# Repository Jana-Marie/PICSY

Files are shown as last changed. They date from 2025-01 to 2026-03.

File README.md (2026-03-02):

# PICSY

**UNDER DEVELOPMENT...**

An ESP32 based Pixel-Art-Camera, shooting color-indexed pixel art alike PNGs directly onto an SD card.

<table>
  <tbody>
    <tr>
      <td colspan="2">
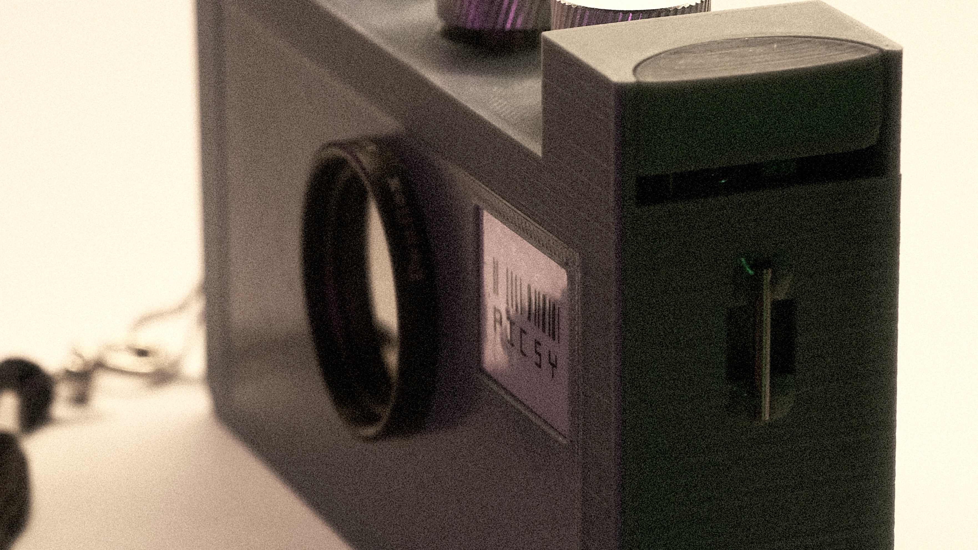
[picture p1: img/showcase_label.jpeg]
        
      </td>
    </tr>
    <tr>
      <td>
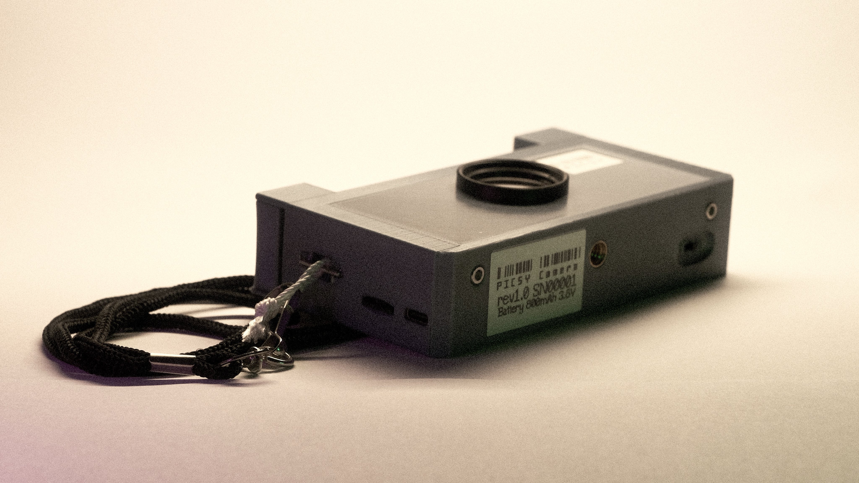
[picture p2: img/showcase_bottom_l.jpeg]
        
      </td>
      <td>
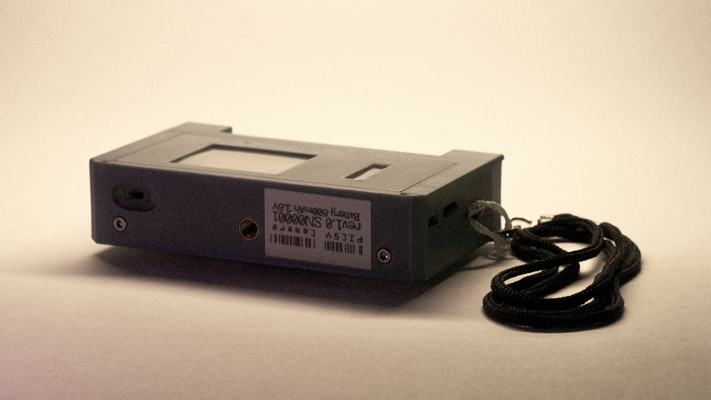
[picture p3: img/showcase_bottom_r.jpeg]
        
      </td>
    </tr>
    <tr>
      <td colspan="2">
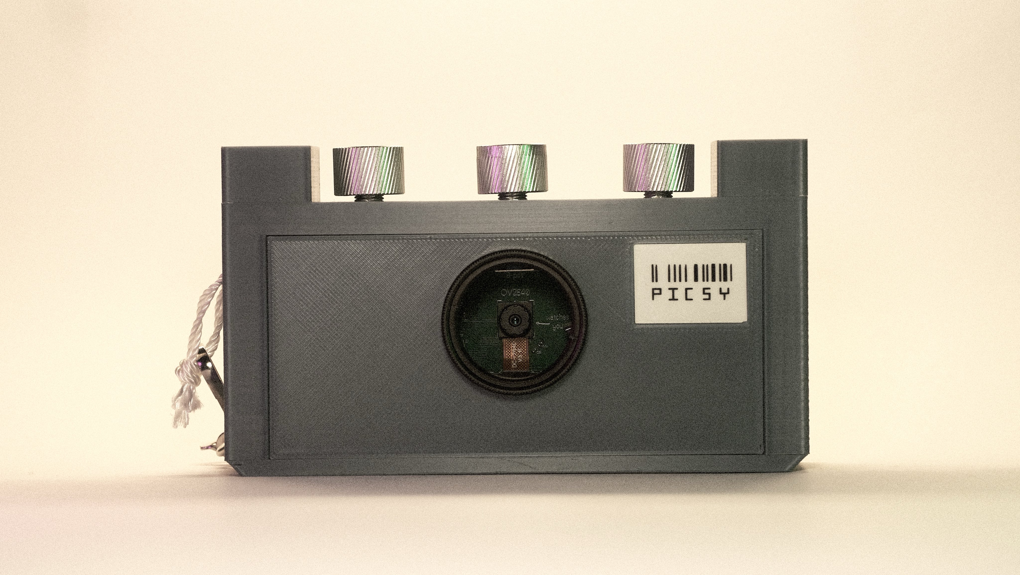
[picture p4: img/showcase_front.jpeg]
        
      </td>
    </tr>
    <tr>
      <td colspan="2">
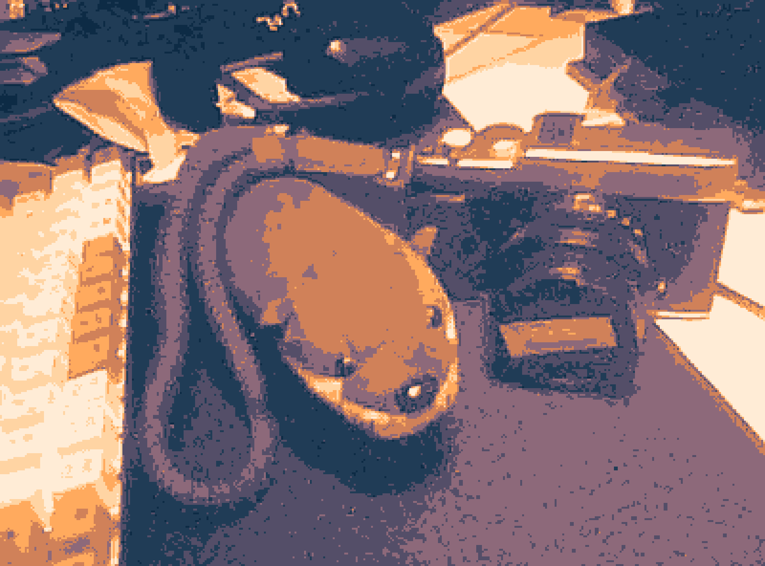
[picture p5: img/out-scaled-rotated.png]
        
      </td>
    </tr>
    <tr>
      <td>
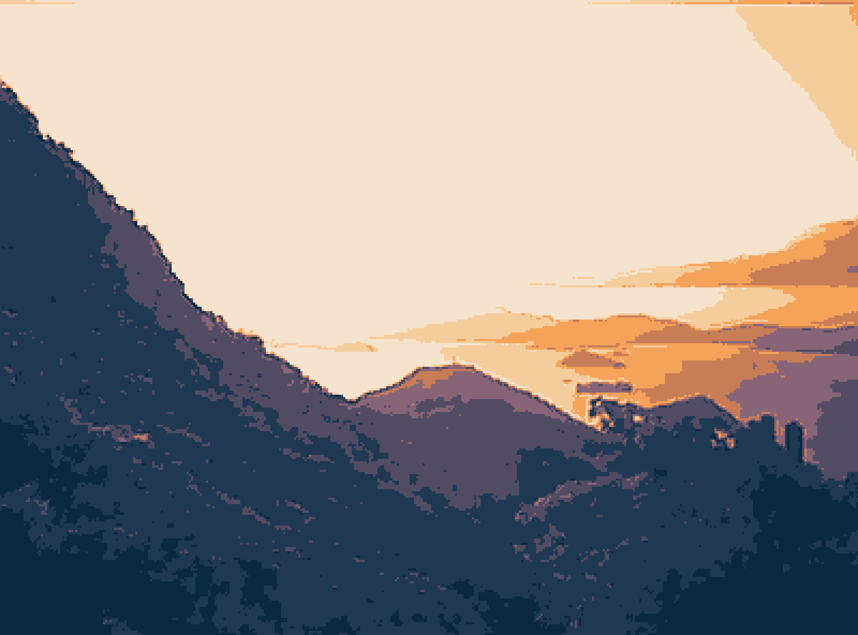
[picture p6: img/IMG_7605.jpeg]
        
      </td>
      <td>
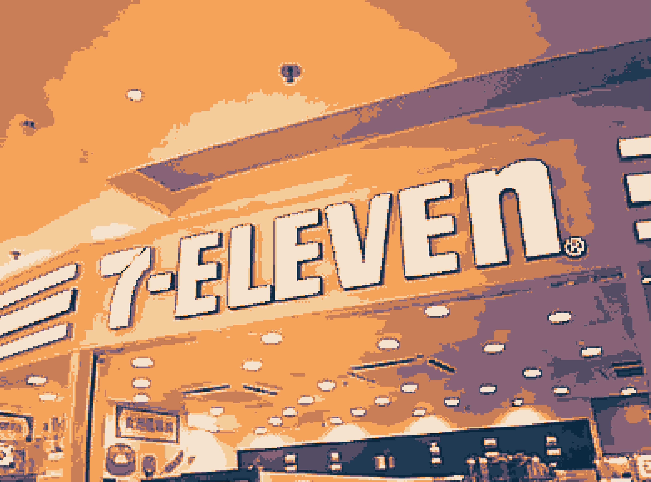
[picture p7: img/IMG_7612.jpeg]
        
      </td>
    </tr>
    <tr>
      <td colspan="2">
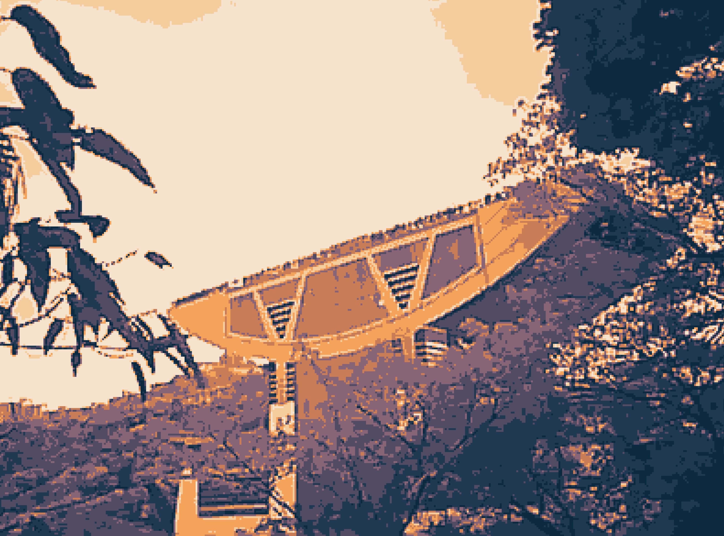
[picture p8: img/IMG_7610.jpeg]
        
      </td>
    </tr>
  </tbody>
</table>

### Setup

Flash micropython as per [/main/micropython-bin](https://github.com/Jana-Marie/PICSY/tree/main/micropython-bin), afterwards copy `ubuf2png.py` onto the ESP32-CAM with `ampy -p /dev/ttyUSB0 -b 115200 put ubuf2png.py`

### Usage

This is WIP and will be moved to saving the PNG to a SD card directly soon.

#### Manual usage

Place an SD card into the SD-Card slot and run

```
ampy -p /dev/ttyUSB0 -b 115200 run boot.py
```

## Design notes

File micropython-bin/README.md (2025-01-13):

# flashing

```
esptool --chip esp32 erase_flash

esptool --chip esp32 -b 460800 --before default_reset --after hard_reset write_flash --flash_mode dio --flash_size 4MB --flash_freq 40m 0x1000 bootloader.bin 0x8000 partition-table.bin 0x10000 micropython.bin
```

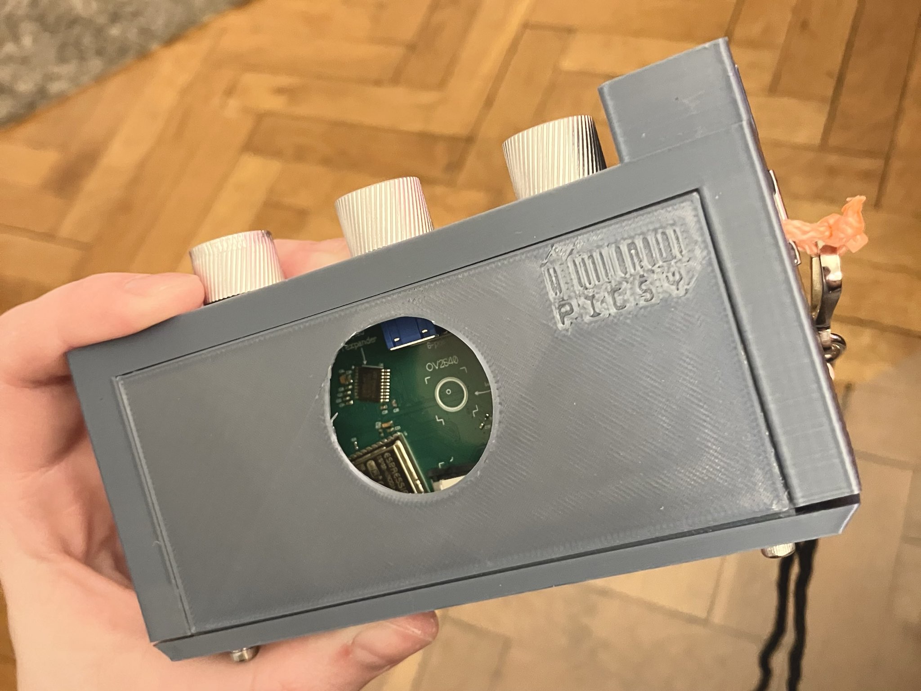
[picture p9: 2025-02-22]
img/wip_3.jpeg

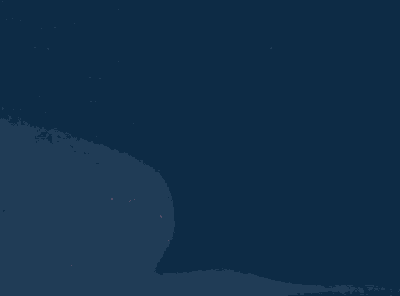
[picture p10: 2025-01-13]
img/out.png

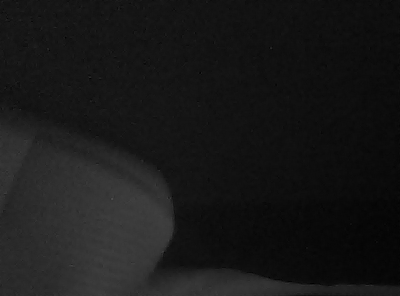
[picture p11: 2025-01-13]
img/img.png

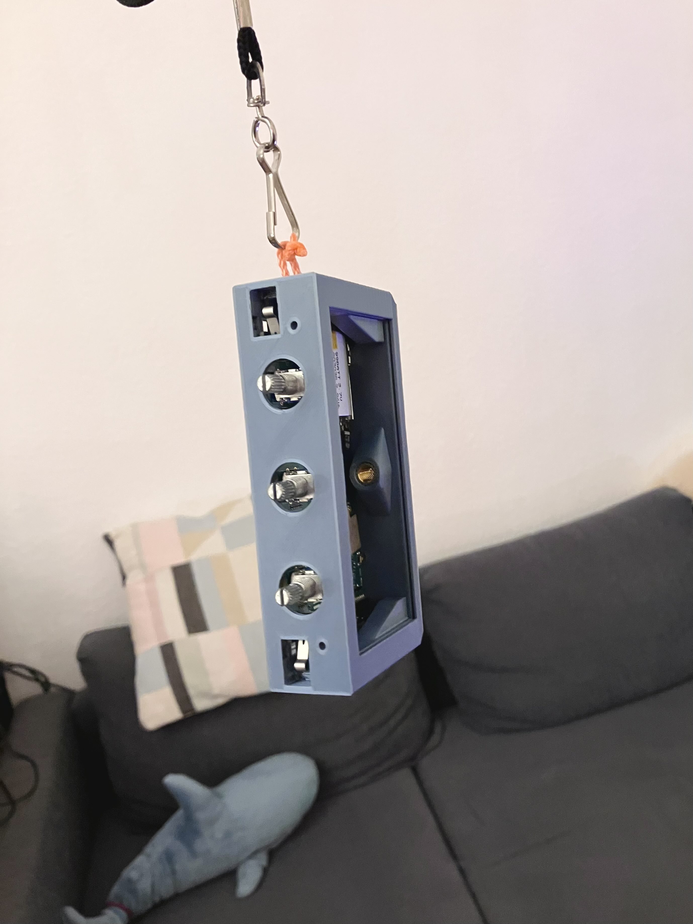
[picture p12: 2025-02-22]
img/wip_2.jpeg

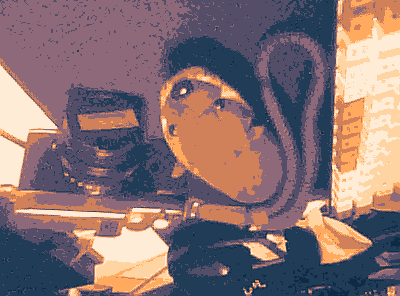
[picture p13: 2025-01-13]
img/out2.png

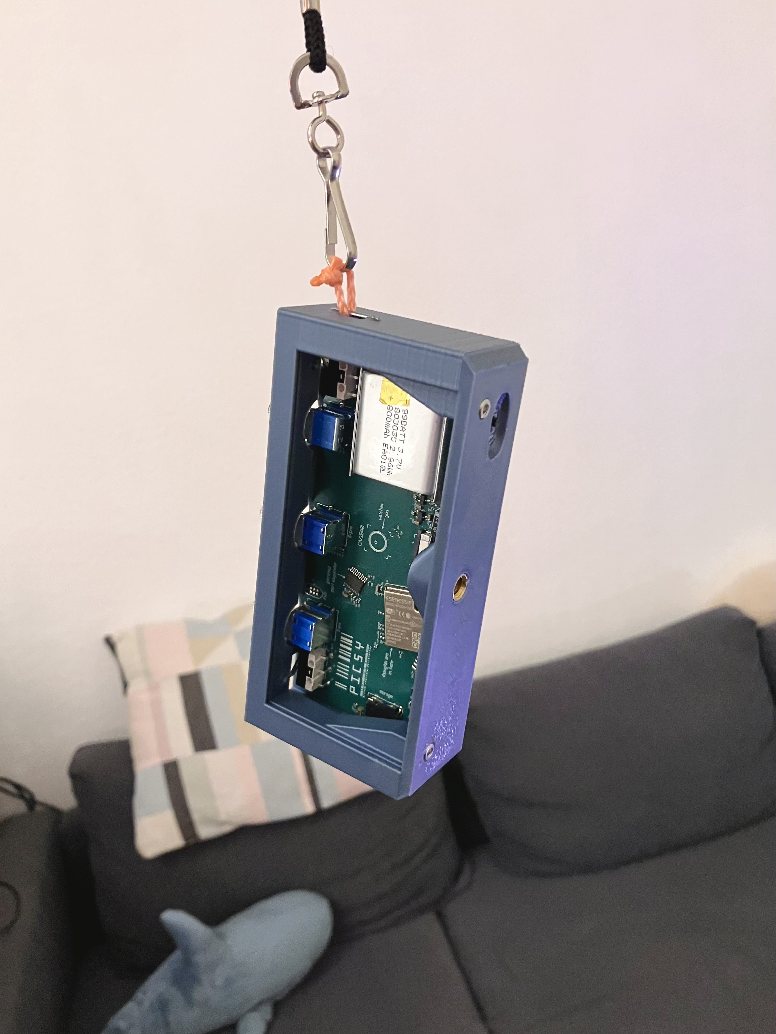
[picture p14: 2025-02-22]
img/wip_1.jpeg

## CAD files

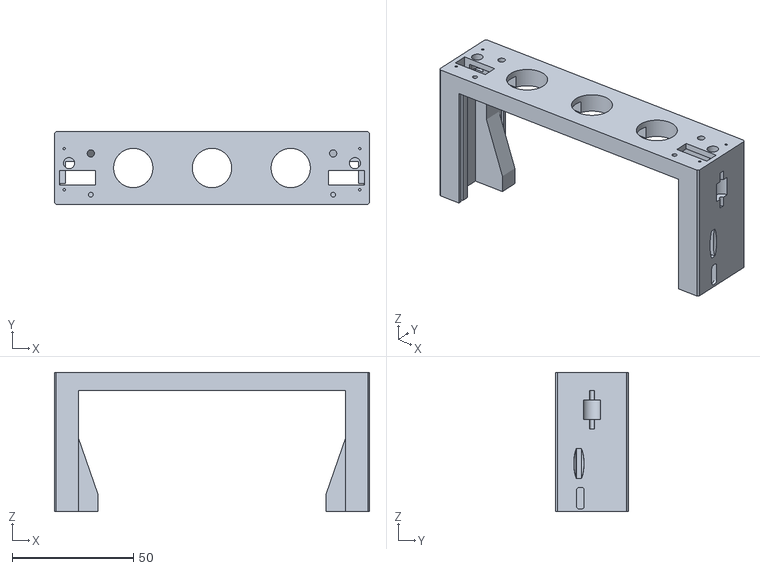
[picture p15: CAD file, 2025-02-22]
CAD/STL/PICSY_main_body.stl
130.0 x 30.0 x 57.4

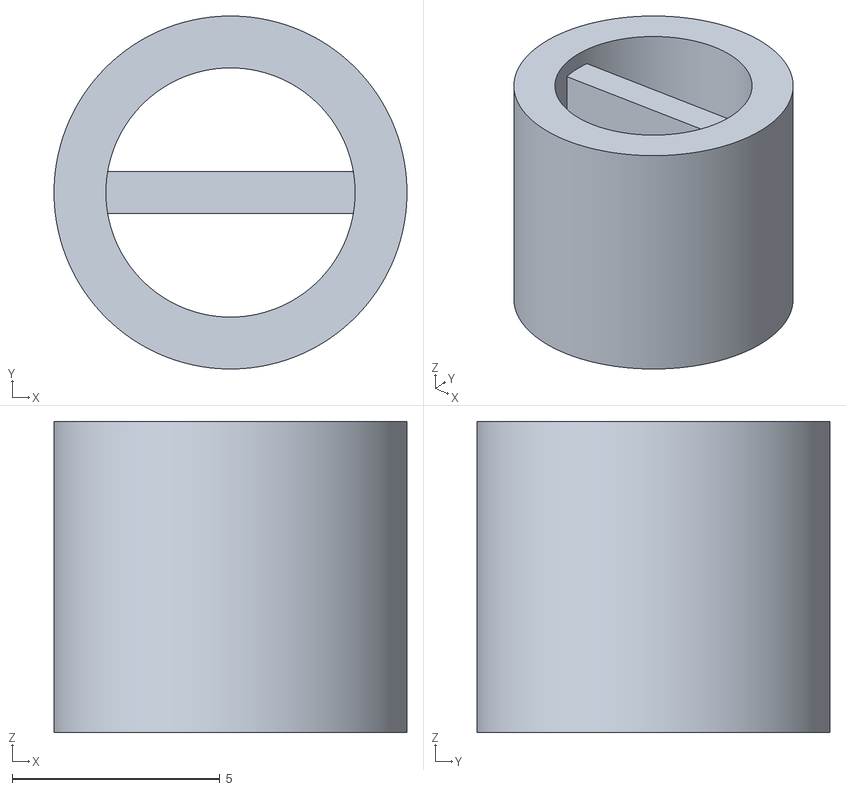
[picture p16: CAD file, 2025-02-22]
CAD/STL/PICSY_button_inlay.stl
8.50 x 8.50 x 7.50

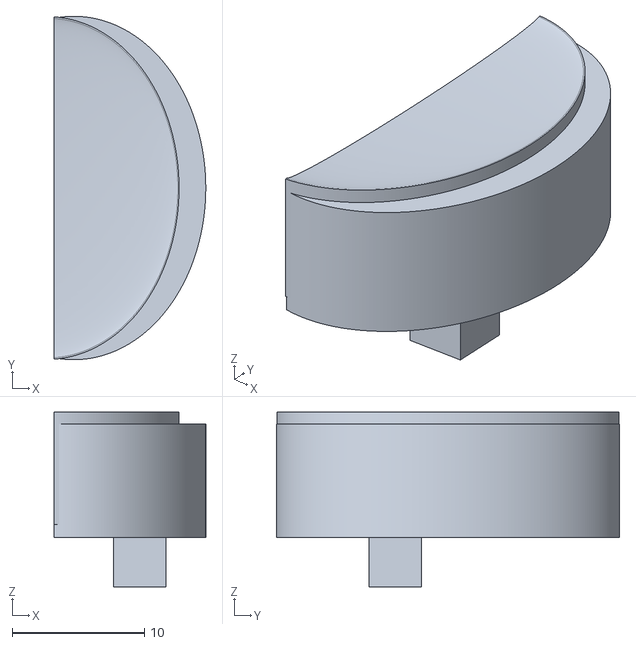
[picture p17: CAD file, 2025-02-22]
CAD/STL/PICSY_trigger_button_r.stl
11.5 x 26.0 x 13.2

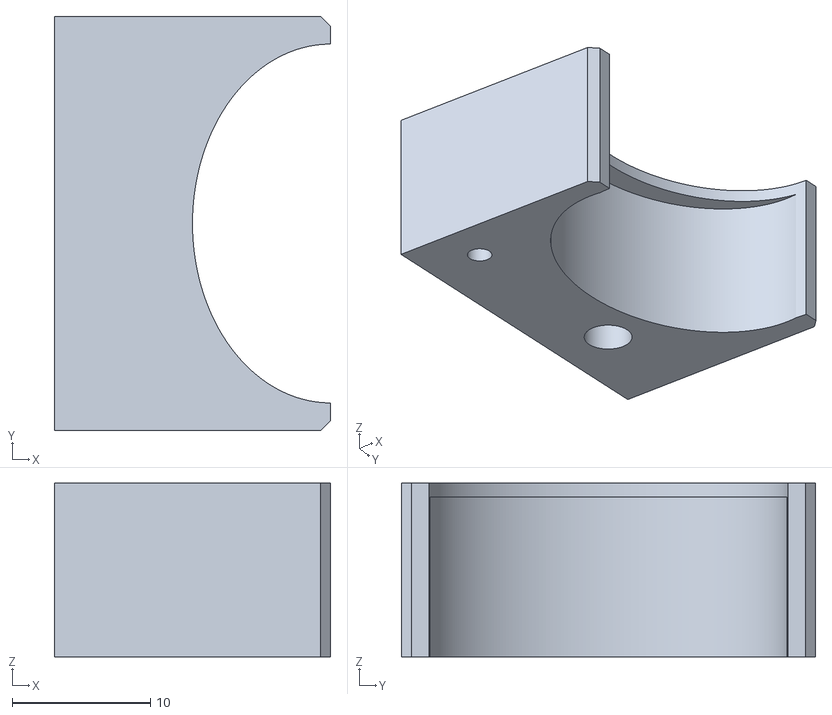
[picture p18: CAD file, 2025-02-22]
CAD/STL/PICSY_trigger_body_l.stl
20.0 x 30.0 x 12.6

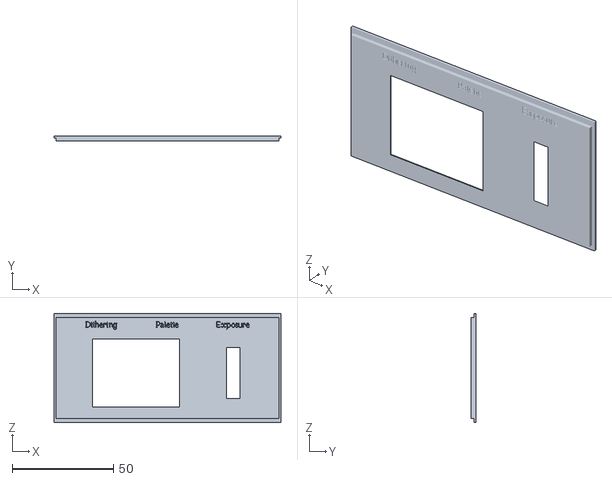
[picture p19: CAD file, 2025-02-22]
CAD/STL/PICSY_back_plate.stl
112.0 x 2.50 x 54.0

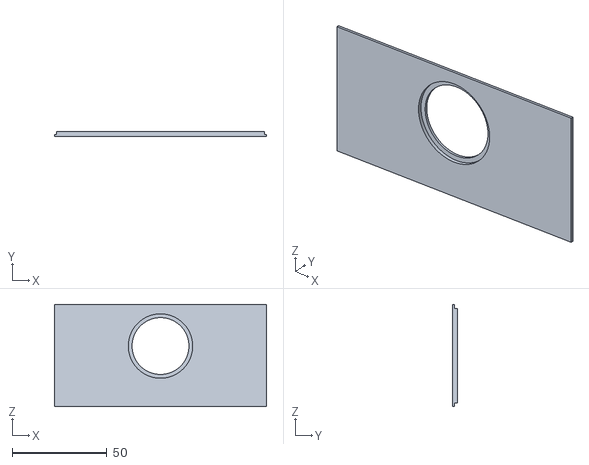
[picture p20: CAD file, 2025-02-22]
CAD/STL/PICSY_front_plate.stl
112.0 x 2.50 x 54.0

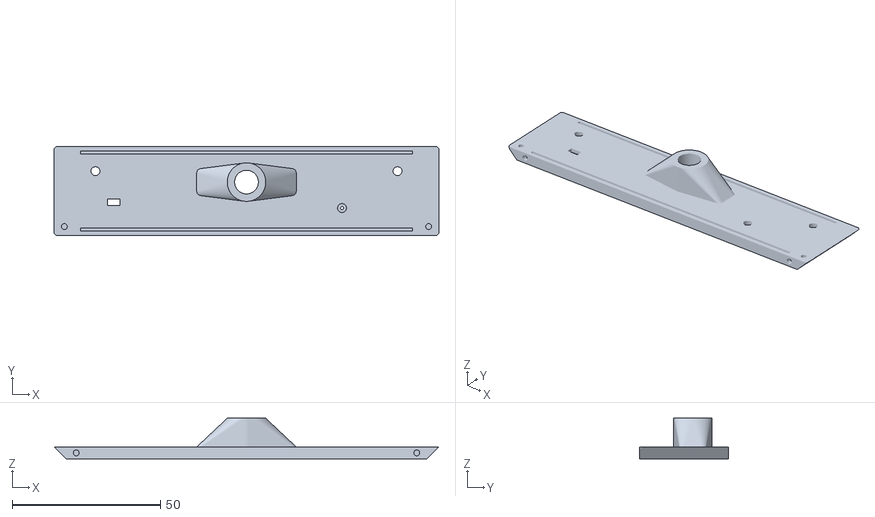
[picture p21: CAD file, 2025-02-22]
CAD/STL/PICSY_bottom_cover.stl
130.0 x 30.0 x 13.7

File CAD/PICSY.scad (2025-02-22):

$fn=30;

if($preview){
  *translate([0,-6.4,0])rotate([90,0,0])picsy_hw(2);
  assembly();
}else{
  $fn=300;
  *mirror([0,0,0])translate([130/2,0,70])trigger_body();
  *mirror([0,0,0])translate([130/2,0,70])trigger_button();
  front_plate();
}

// ######## assembly ########
module assembly(){
  main_body(true);
  translate([0,0,0])trigger_button_body_l();
  translate([0,0,0])trigger_button_body_r();
  translate([0,-12.5,0])back_plate();
  translate([0,12.5,0])front_plate();
  bh=4;
  translate([0,0,-bh])bottom_cover(bh);
}

// ######## main ########
module main_body(finish=false){
  h=70-12.6;
  t=30;l=130;
  color("MediumAquamarine")
  difference(){
    union(){
      // main body
      translate([0,0,h/2])cube([l,t,h],center=true);
    }union(){
      // main notch
      translate([0,0,50/2-0.1])cube([110,t+2,50.1],center=true);
      // flaps
      translate([0,t/2-2,52.2/2])cube([112.2,1,52.2],center=true);
      translate([0,-t/2+2,52.2/2])cube([112.2,1,52.2],center=true);
      // pcb & parts
      translate([0,-7.3,55/2-0.1])cube([125.6,1.75,55.4],center=true);
      translate([0,-7.3+4,55/2-0.1])cube([121,12,55.1],center=true);
      // usb-port
      usbcd=2.5;
      translate([60,3.2/2-6.4,4.5+1])rotate([0,90,0])minkowski(){
        cylinder(d=usbcd,h=1);
        cube([9-usbcd,3.2-usbcd,9.5],center=true);
      }
      translate([58,3.2/2-6.4,4.5+1-5.5])rotate([0,90,0])minkowski(){
        cylinder(d=usbcd,h=1);
        cube([20-usbcd,3.2-usbcd,9.5],center=true);
      }
      // sd card
      translate([l/2,2/2-6.4,5+14.8])cube([12.2,2.2,12.4],center=true);
      translate([l/2-9,2/2-6.4,5+8])cube([12.2,2.2,12.4],center=true);
      intersection(){
        translate([l/2,2/2-6.4,5+14.8])scale([2,4.2,14.2])sphere(d=1);
        translate([l/2,2/2-6.4,5+14.8])cube([12,6,12.4],center=true);
      }
      // lanyard
      for(i = [-1:2:1]){
        translate([130/2*i,0,34])cylinder(d=2,h=16);
        translate([130/2*i,0,34+4])cylinder(d=7,h=8);
      }
      // pins
      for(i = [-1:2:1]){
        translate([l/2*i-15*i,-11,h-(18-11.6)])cylinder(d=2,h=18);
        // spring
        translate([l/2*i-6*i,2,h-(18-11.6)])cylinder(d=4.6,h=10);
        // trigger button
        translate([l/2*i-4*i,8,h-10])cylinder(d=1,h=16);
        translate([l/2*i-4*i,-9,h-10])cylinder(d=1,h=16);
      }
      // vertical pins
      for(i = [-1:2:1]){
        translate([(l-7)/2*i,-12,-1.5])rotate([0,0,0])cylinder(d=2,h=30);
      }
      // trigger
      for(i = [-1:2:1]){
        translate([(l/2-15/2-2)*i,-4,-8/2+h+1])cube([15,6,8],center=true);
        *translate([(l/2-15/2-4.5)*i,-8,-4/2+h-1])cube([4,6,4],center=true);
        translate([(l/2-15)*i,6,h-20])cylinder(d=3,h=25);
      }
      // knobs
      for(i = [-1:1:1]){
        translate([32.5*i,0,40])cylinder(d=16.2,h=25);
      }
      // edges
      if(finish){
        corn_z=1;
        for(i = [-1:2:1]){
          for(j = [-1:2:1]){
            translate([l/2*i,t/2*j,h/2])rotate([0,0,45])cube([corn_z,corn_z,h+2],center=true);
          }
        }
      }
    }
  }
  sl=8;
  color("MediumAquamarine")
  for(i = [0:1:1]){
    mirror([i,0,0])
    difference(){
      union(){
        hull(){
          translate([110/2-sl/2,sl/2+2.7,7/2])cube([sl,sl,7],center=true);
          translate([110/2+1/2,sl/2+2.7,30/2])cube([1,sl,30],center=true);
        }
      }union(){
        translate([110/2-sl/2,sl/2+2.7,-0.5])cylinder(d=3.9,h=8);
        translate([110/2-sl/2,sl/2+2.7,-0.5])cylinder(d=4.05,h=2);
      }
    }
  }
}

// ######## bottom cover ########
module bottom_cover(h){
  t=30;l=130;
  color("PaleGoldenrod")
  difference(){
    union(){
      // body
      translate([0,0,h/2])cube([l,t,h],center=true);
      // 1/4"
      hull(){
        translate([0,3,0])cylinder(d=13,h=13.7);
        translate([0,3,1/2])cube([40,8,1],center=true);
      }
    }union(){
      // flaps
      translate([0,t/2-2,-2/2+h])cube([112.2,1,2.2],center=true);
      translate([0,-t/2+2,-2/2+h])cube([112.2,1,2.2],center=true);
      // big corners
      for(i = [-1:2:1]){
        translate([l/2*i,0,0])rotate([0,45,0])cube([sqrt(h*h+h*h),t+2,sqrt(h*h+h*h)],center=true);
      }
      // smol corners
      corn_z=1;
      for(i = [-1:2:1]){
        for(j = [-1:2:1]){
          translate([l/2*i,t/2*j,h/2])rotate([0,0,45])cube([corn_z,corn_z,h+2],center=true);
        }
      }
      // screws
      for(i = [-1:2:1]){
        translate([(110/2-8/2)*i,8/2+2.7,-0.5])cylinder(d=3,h=8);
        translate([(110/2-8/2)*i,8/2+2.7,-0.5])cylinder(d=5.5,h=3.5);
      }
      // horizontal pins
      for(i = [-1:2:1]){
        translate([(l-15)/2*i,10,2])rotate([90,0,0])cylinder(d=2,h=30);
      }
      // vertical pins
      for(i = [-1:2:1]){
        translate([(l-7)/2*i,-12,3])rotate([0,0,0])cylinder(d=2,h=30);
      }
      // reset
      translate([32.25,-5.75,-0.5])cylinder(d=1,h=8);
      translate([32.25,-5.75,h-1.9])cylinder(d=3,h=2);
      // switch
      translate([-44.75,-3.75,h/2])cube([4.22,2.2,h+1],center=true);
      translate([-44.75,-3.75,0])minkowski(){
        cube([4,2,1],center=true);
        scale([14,8,4])sphere(d=1);
      }
      // 1/4"
      translate([0,3,-0.5])cylinder(d=8,h=14.2);
      translate([0,3,-0.5])cylinder(d2=8,d1=9,h=1);
    }
  }
}

// ######## trigger buttons ########
module trigger_button_body_r(){
  mirror([1,0,0])translate([130/2,0,70])trigger_body();
  mirror([1,0,0])translate([130/2,0,70])trigger_button();
}

module trigger_button_body_l(){
  mirror([0,0,0])translate([130/2,0,70])trigger_body();
  *mirror([0,0,0])translate([130/2,0,70])trigger_button();
}

module trigger_body(){
  color("CornflowerBlue")
  difference(){
    union(){
      // height 12.6!!
      translate([-(130-90)/2/2,0,-12.6/2])cube([(130-90)/2,30,12.6],center=true);
      // counter
      *translate([-12,-7.8,-4/2-12.5])cube([3.8,2,4],center=true);
      *hull(){
        translate([-12,-7.8-1,-1/2-12.5-1.2])cube([3.8,2,1],center=true);
        translate([-12,-7.8,1/2-12.5-4])cube([3.8,2,1],center=true);
      }
    }union(){
      // cutouts
      translate([0,0,-13.6])scale([20,26,1])cylinder(d=1,h=14.6);
      translate([-2,0,-13.6])scale([20,26,1])cylinder(d=1,h=12.6);
      *intersection(){
        translate([0,0,-15])scale([20,26,1])cylinder(d=1,h=25);
        translate([-20/2-0.5,0,-12.8/2-0.1])cube([20,30,12.8],center=true);
      }
      translate([0,0,0])cube([1.5,1.5,10],center=true);
      // screw
      translate([-15,6,-0.5-12.6])cylinder(d=3.9,h=9);
      // pin
      translate([-15,-11,-19])cylinder(d=2,h=18);
      // edges
      corn_z=1;
      for(j = [-1:2:1]){
        translate([0,30/2*j,-12.6/2])rotate([0,0,45])cube([corn_z,corn_z,12.6+2],center=true);
      }
    }
  }
}

module trigger_button(){
  color("IndianRed")
  difference(){
    union(){
      // main button
      intersection(){
        translate([0,0,-8.6])scale([19.95,25.95,1])cylinder(d=1,h=9.6);
        translate([-20/2-0.5,0,-12.8/2-0.1])cube([19.95,29,12.8],center=true);
      }
      intersection(){
        translate([-2,0,-9.6])scale([20,26,1])cylinder(d=1,h=8.6);
        translate([-20/2-0.5,0,-12.8/2-0.1])cube([19.95,29,12.8],center=true);
      }
      // microswitch contactor
      translate([-4/2-5,-4,2.5/2-12.6])cube([4,4,4],center=true);
      *translate([-10/2-3,-4,-2.5/2-12.6])cube([10,4,2.5],center=true);
      *hull(){
        translate([-4/2-3,-4,2.5/2-12.6])cube([4,4,2.5],center=true);
        translate([-4/2-1,-2,-2.5/2-5])cube([4,15,2.5],center=true);
      }
    }union(){
      // sink for finger
      translate([0,0,0])scale([19.95,25.95,1.5])sphere(d=1);
      // spring
      translate([-6,2,-12])cylinder(d=4.6,h=10);
      // pins
      translate([-4,8,-17.5])cylinder(d=1,h=16);
      translate([-4,-9,-17.5])cylinder(d=1,h=16);
    }
  }
}

// ######## plates ########
module front_plate(){
  color("RosyBrown")
  difference(){
    union(){
      translate([0,1/2,54/2-2])cube([112,1,54],center=true);
      translate([0,1.5/2+1,49.8/2])cube([109.8,1.5,49.8],center=true);
    }union(){
      // lens
      translate([0,-1,30])rotate([-90,0,0])cylinder(d=30,h=6);
      //translate([0,-1,30])rotate([-90,0,0])cylinder(d=34,h=2.5);
      // text
      //translate([-29,2.2,36])rotate([90,0,180])linear_extrude(height=0.5)text("PICSY", font="Pixelary");
      translate([-39,1/2+1.8,38])cube([25,1,18],center=true);
    }
  }
   if($preview){
    translate([0,3,30])rotate([-90,0,0])uv_filter_30mm();
  }
}
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

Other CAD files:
CAD/STL/PICSY_trigger_button_l.stl
CAD/STL/PICSY_trigger_body_r.stl
CAD/STL/PICSY_front_plate_empty_square.stl

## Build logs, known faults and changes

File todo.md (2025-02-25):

- **ESP32**
  - [ ] Image processing
    - [x] ~~Fix buffer swap issue, check if it still persists~~
    - [ ] Increase processing speed
  - [ ] UI
    - [x] ~~Trigger pin irq~~
    - [ ] Somehow upscale images by 4x
      - Added an external upscaler via js/html for now!
    - [ ] Add webserver to view and transmit images
    - [ ] Add palette display driver
    - [ ] Implement palette display UI
    - [ ] Add live-view display driver
    - [ ] Implement live view
    - [ ] Bodge an LED until next PCB rev
  - [ ] Coprocessor
    - [x] ~~Read trigger pin~~
    - [ ] Add co-processor communication (I2C)
    - [ ] Co-processor flashing via I2C
  - [ ] Settings
    - [x] ~~add camera settings code~~
    - [ ] Read settings from SD card (YAML/JSON)
    - [ ] Add more, selectable color palettes
    - [ ] Add dithering (InDi)
    - [ ] Nearest color matching, if possible
  - [ ] Misc
    - [ ] Check SD interface speed, is single lane fast enough to free pins?

- **STM32**
  - [x] ~~Add initial fw~~
  - [ ] I2C
    - [x] ~~Implement functionality~~
    - [x] ~~Define registermap~~
    - [ ] Sticky interrupts for rotary switches
  - [x] ~~ADC~~
    - [x] ~~Add all ADC channels~~
    - [x] ~~Bin the rotary encoders~~
    - [x] ~~Implement VBAT calculation~~
  - [x] ~~Trigger pins~~
    - [x] ~~Add l-r trigger pins~~
    - [x] ~~have a direct trigger pin interrup pass-through~~
  - [x] ~~Displays~~
    - [x] ~~Add CS pins, inactive high~~
    - [x] ~~Add RST pin~~
  - [ ] I2C bootloader

- **Hardwre**
  - [ ] rev1.1
    - [x] ~~Fix PSRAM layout in schematic~~
    - [x] ~~Cam clock pin 100nF → 15nF~~
    - [ ] Add status LEDs
    - [ ] Add display backlight control
    - [ ] Update ESP32 to a more modern module with internal PSRAM
    - [x] ~~Swap UART pins~~
    - [ ] Implement changes on PCB
    - [ ] PCB font sizes are too small
    - [ ] STM32 nRST pin needs pullup
    - [ ] Display 2 has the wrong connector
  - [ ] Clean up schematic
  - [ ] DFM

- **Web**
  - [ ] Build an image upscaler
    - [x] Build a web-app
    - [ ] Embed it onto the ESP32
    - [ ] Add boot screens for web-app solution

- **Documentation**
  - [ ] Add documentation as we go along

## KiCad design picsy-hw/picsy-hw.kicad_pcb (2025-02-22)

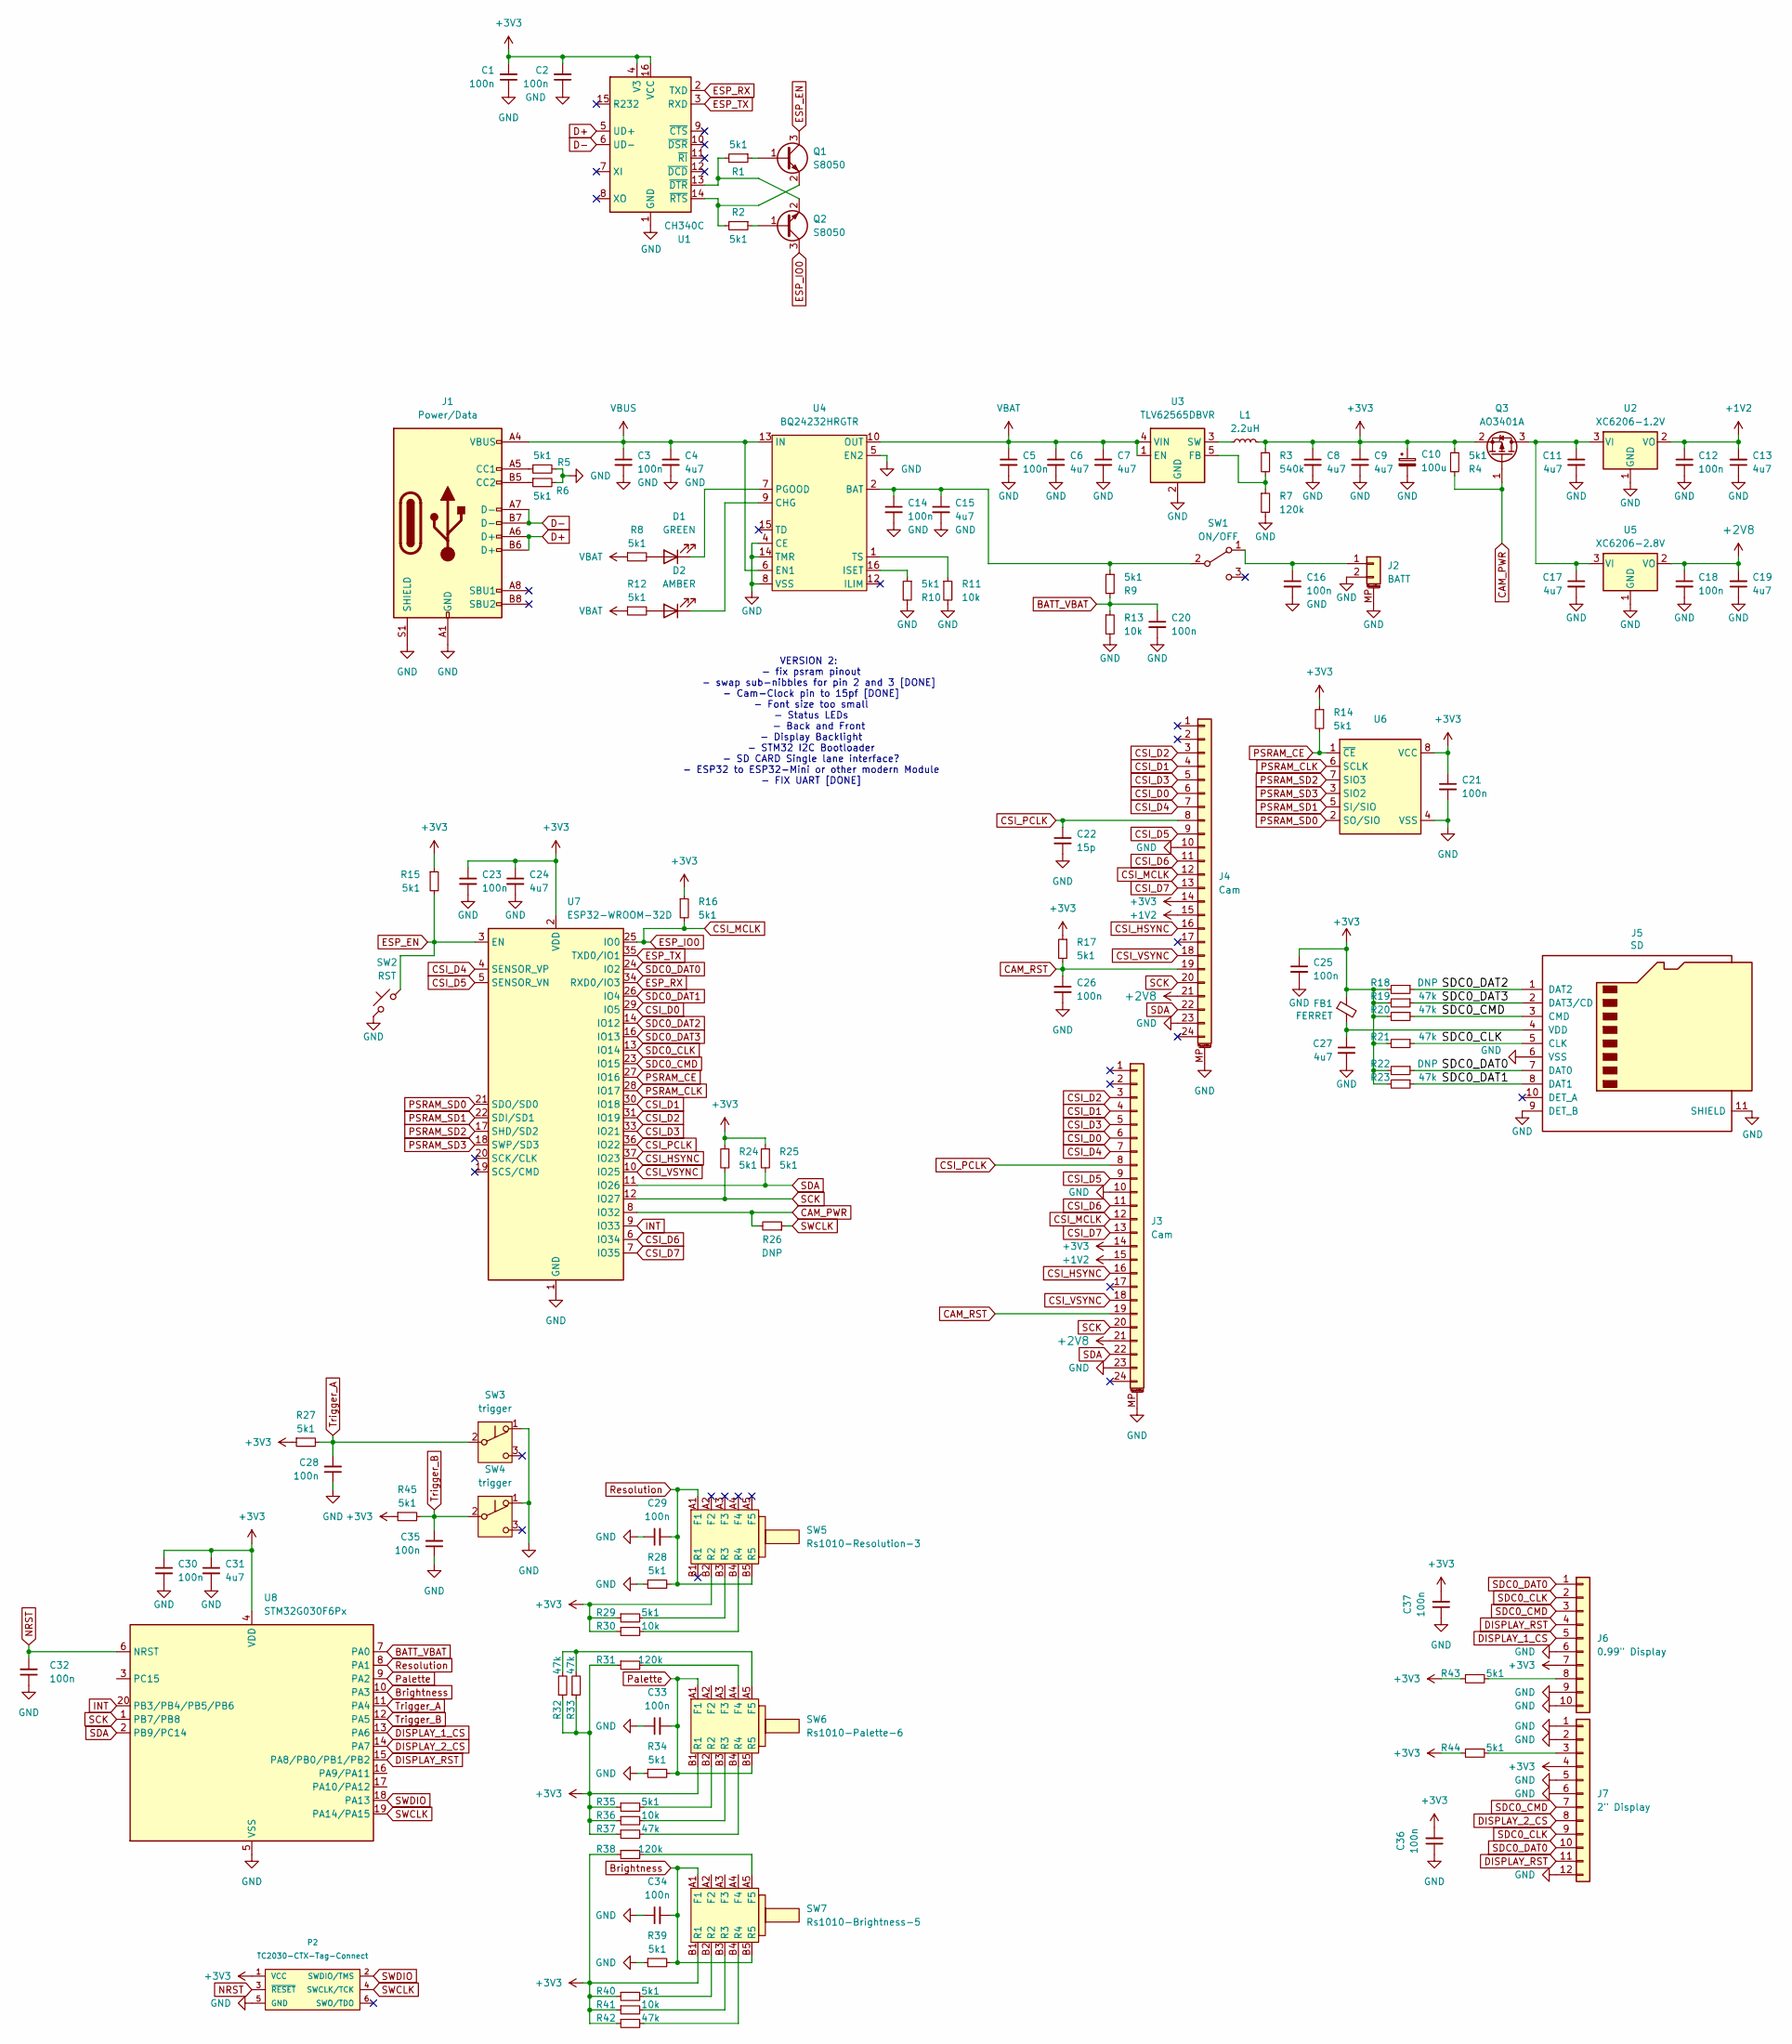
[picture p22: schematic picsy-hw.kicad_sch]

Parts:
C1, C2, C3, C5, C12, C14, C16, C18, C20, C21, C23, C25, C26, C28, C29, C30, C32, C33, C34, C35, C36, C37: 100n; C_0402
C4, C6, C7, C8, C9, C11, C13, C15, C17, C19, C24, C27, C31: 4u7; C_0603
C10: 100u; CP_Elec_6.3x5.4
C22: 15p; C_0402
D1: GREEN; LED_0603_1608Metric
D2: AMBER; LED_0603_1608Metric
FB1: FERRET; R_0805
J1: Power/Data; USB-C 16Pin
J2: BATT; Molex_PicoBlade_53261-0271_1x02-1MP_P1.25mm_Horizontal
J3, J4: Cam; TE_2-1734839-4_1x24-1MP_P0.5mm_Horizontal
J5: SD; microSD_HC_Hirose_DM3D-SF
J6: 0.99" Display; 0.99Inch-IPS-GC9D01
J7: 2" Display; 2.0Inch-IPS-ST7789
L1: 2.2uH; L_2512_6332Metric
P2: TC2030-CTX-Tag-Connect; TC2030
Q1, Q2: S8050; SOT-23
Q3: AO3401A; SOT-23
R1, R2, R4, R5, R6, R8, R9, R10, R12, R14, R15, R16, R17, R24, R25, R27, R28, R29, R34, R35, R39, R40, R43, R44, R45: 5k1; R_0402
R3: 540k; R_0402
R7, R31, R38: 120k; R_0402
R11, R13, R30, R36, R41: 10k; R_0402
R18, R22, R26: DNP; R_0402
R19, R20, R21, R23, R32, R33, R37, R42: 47k; R_0402
SW1: ON/OFF; SK-12D07VG4
SW2: RST; SW_SPST_EVQP7C
SW3: trigger; Microswitch_L
SW4: trigger; Microswitch_R
SW5: Rs1010-Resolution-3; Rs1010
SW6: Rs1010-Palette-6; Rs1010
SW7: Rs1010-Brightness-5; Rs1010
U1: CH340C; SOIC-16_3.9x9.9mm_P1.27mm
U2: XC6206-1.2V; SOT-23-3
U3: TLV62565DBVR; SOT-23-5
U4: BQ24232HRGTR; QFN-16-1EP_3x3mm_P0.5mm_EP1.7x1.7mm
U5: XC6206-2.8V; SOT-23-3
U6: SOIC-8_3.9x4.9mm_P1.27mm
U7: ESP32-WROOM-32D; ESP32-WROOM-32U
U8: STM32G030F6Px; TSSOP-20_4.4x6.5mm_P0.65mm

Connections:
+1V2: C12.1, C13.2, J3.15, J4.15, U2.2 (VO)
+2V8: C18.1, C19.2, J3.21, J4.21, U5.2 (VO)
+3V3: C1.2, C2.2, C8.1, C9.1, C10.1, C21.1, C23.1, C24.1, C25.1, C30.1, C31.1, C36.2, C37.2, FB1.1, J3.14, J4.14, J6.7, J7.4, L1.2, P2.1 (VCC), Q3.2 (S), R3.1, R4.1, R14.1, R15.1, R16.1, R17.1, R18.2, R19.2, R20.2, R21.2, R22.2, R23.2, R24.1, R25.1, R27.1, R29.1, R30.1, R31.1, R32.1, R33.1, R35.1, R36.1, R37.1, R38.1, R40.1, R41.1, R42.1, R43.1, R44.1, R45.1, SW5.B2 (R2), SW6.B1 (R1), SW7.B1 (R1), U1.4 (V3), U1.16 (VCC), U6.8 (VCC), U7.2 (VDD), U8.4 (VDD)
BATT_VBAT: C20.1, R9.2, R13.1, U8.7 (PA0)
Brightness: C34.2, R39.2, SW7.A1 (F1), SW7.B5 (R5), U8.10 (PA3)
CAM_PWR: Q3.1 (G), R4.2, R26.2, U7.8 (IO32)
CAM_RST: C26.1, J3.19, J4.19, R17.2
CSI_D0: J3.6, J4.6, U7.29 (IO5)
CSI_D1: J3.4, J4.4, U7.30 (IO18)
CSI_D2: J3.3, J4.3, U7.31 (IO19)
CSI_D3: J3.5, J4.5, U7.33 (IO21)
CSI_D4: J3.7, J4.7, U7.4 (SENSOR_VP)
CSI_D5: J3.9, J4.9, U7.5 (SENSOR_VN)
CSI_D6: J3.11, J4.11, U7.6 (IO34)
CSI_D7: J3.13, J4.13, U7.7 (IO35)
CSI_HSYNC: J3.16, J4.16, U7.37 (IO23)
CSI_MCLK: J3.12, J4.12, Q2.3 (C), R16.2, U7.25 (IO0)
CSI_PCLK: C22.1, J3.8, J4.8, U7.36 (IO22)
CSI_VSYNC: J3.18, J4.18, U7.10 (IO25)
D+: J1.A6 (D+), J1.B6 (D+), U1.5 (UD+)
D-: J1.A7 (D-), J1.B7 (D-), U1.6 (UD-)
DISPLAY_1_CS: J6.5, U8.13 (PA6)
DISPLAY_2_CS: J7.8, U8.14 (PA7)
DISPLAY_RST: J6.4, J7.11, U8.15 (PA8/PB0/PB1/PB2)
ESP_EN: Q1.3 (C), R15.2, SW2.1, U7.3 (EN)
GND: C1.1, C2.1, C3.2, C4.2, C5.2, C6.2, C7.2, C8.2, C9.2, C10.2, C11.2, C12.2, C13.1, C14.2, C15.2, C16.2, C17.2, C18.2, C19.1, C20.2, C21.2, C22.2, C23.2, C24.2, C25.2, C26.2, C27.2, C28.1, C29.1, C30.2, C31.2, C32.1, C33.1, C34.1, C35.1, C36.1, C37.1, J1.A1 (GND), J1.A12 (GND), J1.B1 (GND), J1.B12 (GND), J1.S1 (SHIELD), J2.2, J2.MP (MountPin), J3.10, J3.23, J3.MP (MountPin), J4.10, J4.23, J4.MP (MountPin), J5.6 (VSS), J5.9 (DET_B), J5.11 (SHIELD), J6.6, J6.9, J6.10, J7.1, J7.2, J7.5, J7.6, J7.12, P2.5 (GND), R5.2, R6.2, R7.2, R10.2, R11.2, R13.2, R28.1, R34.1, R39.1, SW2.2, SW3.1 (A), SW4.1 (A), U1.1 (GND), U2.1 (GND), U3.2 (GND), U4.4 (CE), U4.5 (EN2), U4.8 (VSS), U4.14 (TMR), U4.17 (VSS), U5.1 (GND), U6.4 (VSS), U7.1 (GND), U7.15 (GND), U7.38 (GND), U7.39 (GND), U8.5 (VSS)
INT: U7.9 (IO33), U8.20 (PB3/PB4/PB5/PB6)
NRST: C32.2, P2.3 (~RESET), U8.6 (NRST)
unnamed: D1.2 (A), R8.2
unnamed: D1.1 (K), U4.7 (PGOOD)
unnamed: D2.2 (A), R12.2
unnamed: D2.1 (K), U4.9 (CHG)
unnamed: J1.A5 (CC1), R5.1
unnamed: J1.B5 (CC2), R6.1
unnamed: C16.1, J2.1, SW1.1 (A)
unnamed: C27.1, FB1.2, J5.4 (VDD)
unnamed: J6.8, R43.2
unnamed: J7.3, R44.2
unnamed: Q1.1 (B), R1.1
unnamed: Q1.2 (E), R2.2, U1.14 (~RTS)
unnamed: Q2.1 (B), R2.1
unnamed: Q2.2 (E), R1.2, U1.13 (~DTR)
unnamed: C11.1, C17.1, Q3.3 (D), U2.3 (VI), U5.3 (VI)
unnamed: C14.1, C15.1, R9.1, SW1.2 (B), U4.2 (BAT), U4.3 (BAT)
unnamed: R29.2, SW5.B3 (R3)
unnamed: R30.2, SW5.B4 (R4)
unnamed: R31.2, SW6.A4 (F4)
unnamed: R32.2, R33.2, SW6.A5 (F5)
unnamed: R35.2, SW6.B2 (R2)
unnamed: R36.2, SW6.B3 (R3)
unnamed: R37.2, SW6.B4 (R4)
unnamed: R38.2, SW7.A5 (F5)
unnamed: R40.2, SW7.B2 (R2)
unnamed: R41.2, SW7.B3 (R3)
unnamed: R42.2, SW7.B4 (R4)
unnamed: R3.2, R7.1, U3.5 (FB)
unnamed: L1.1, U3.3 (SW)
unnamed: R10.1, U4.16 (ISET)
unnamed: R11.1, U4.1 (TS)
PSRAM_CE: R14.2, U6.1 (~CE), U7.27 (IO16)
PSRAM_CLK: U6.6 (SCLK), U7.28 (IO17)
PSRAM_SD0: U6.2 (SO/SIO), U7.21 (SDO/SD0)
PSRAM_SD1: U6.5 (SI/SIO), U7.22 (SDI/SD1)
Palette: C33.2, R34.2, SW6.A1 (F1), SW6.B5 (R5), U8.9 (PA2)
Resolution: C29.2, R28.2, SW5.A1 (F1), SW5.B5 (R5), U8.8 (PA1)
SCK: J3.20, J4.20, R24.2, U7.12 (IO27), U8.1 (PB7/PB8)
SDA: J3.22, J4.22, R25.2, U7.11 (IO26), U8.2 (PB9/PC14)
SDC0_CLK: J5.5 (CLK), J6.2, J7.9, R21.1, U7.13 (IO14)
SDC0_CMD: J5.3 (CMD), J6.3, J7.7, R20.1, U7.23 (IO15)
SDC0_DAT0: J5.7 (DAT0), J6.1, J7.10, R22.1, U7.24 (IO2)
SDC0_DAT1: J5.8 (DAT1), R23.1, U7.26 (IO4)
SDC0_DAT2: J5.1 (DAT2), R18.1, U7.14 (IO12)
SDC0_DAT3: J5.2 (DAT3/CD), R19.1, U7.16 (IO13)
SWCLK: P2.4 (SWCLK/TCK), R26.1, U8.19 (PA14/PA15)
SWDIO: P2.2 (SWDIO/TMS), U8.18 (PA13)
Trigger_A: C28.2, R27.2, SW3.2 (B), U8.11 (PA4)
Trigger_B: C35.2, R45.2, SW4.2 (B), U8.12 (PA5)
VBAT: C5.1, C6.1, C7.1, R8.1, R12.1, U3.1 (EN), U3.4 (VIN), U4.10 (OUT), U4.11 (OUT)
VBUS: C3.1, C4.1, J1.A4 (VBUS), J1.A9 (VBUS), J1.B4 (VBUS), J1.B9 (VBUS), U4.6 (EN1), U4.13 (IN)

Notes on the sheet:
VERSION 2: - fix psram pinout - swap sub-nibbles for pin 2 and 3 [DONE] - Cam-Clock pin to 15pf [DONE] - Font size too small - Status LEDs - Back and Front - Display Backlight - STM32 I2C Bootloader - SD CARD Single lane interface? - ESP32 to ESP32-Mini or other modern Module - FIX UART [DONE]

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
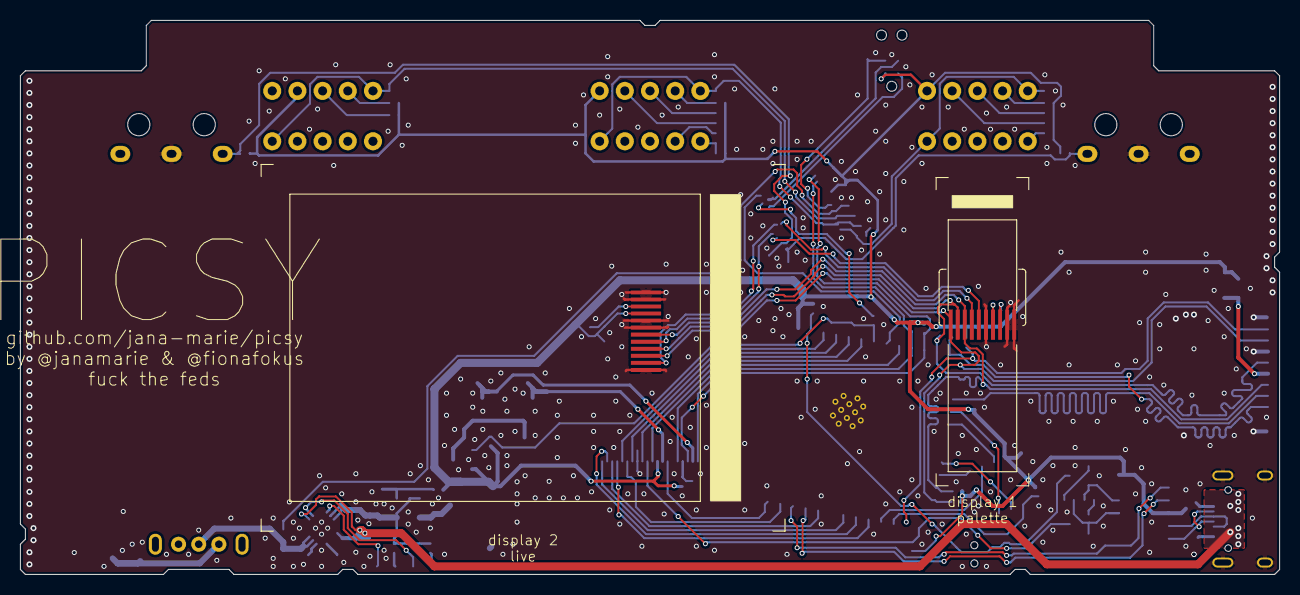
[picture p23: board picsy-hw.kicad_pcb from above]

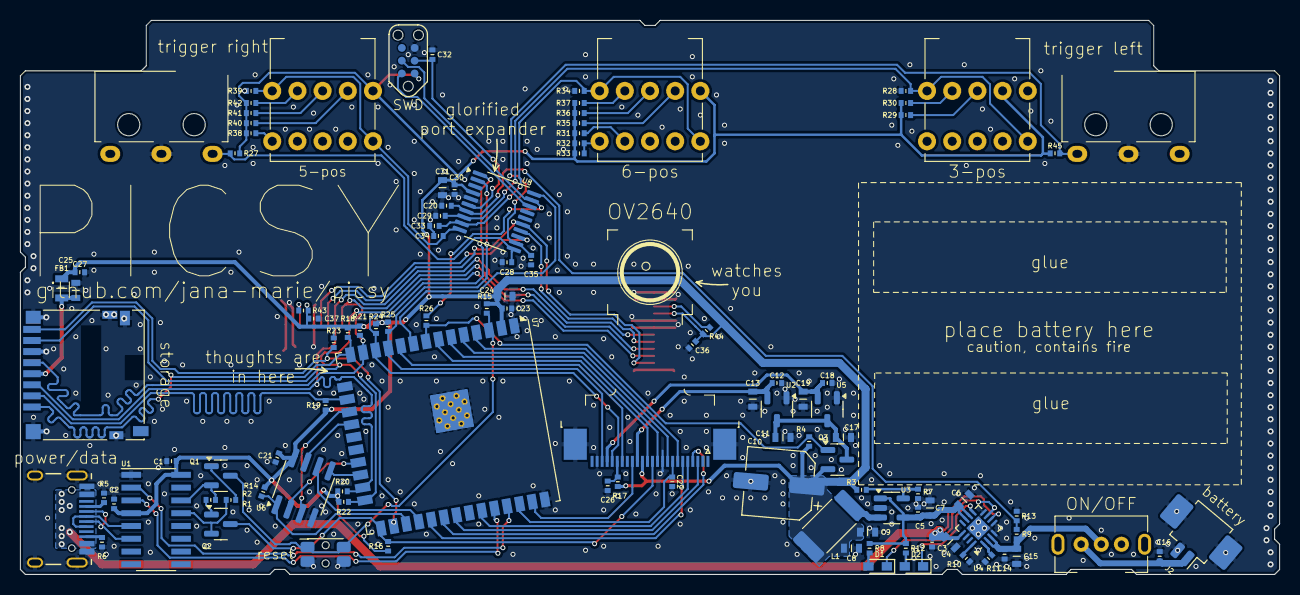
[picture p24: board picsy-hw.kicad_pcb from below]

Board: 2 copper layers, 125.0 x 55.0 mm, 111 parts (109 on the bottom side), 83 nets.

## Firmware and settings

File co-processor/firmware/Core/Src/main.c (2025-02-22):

#include "main.h"
#include "i2c_client.h"
#include "i2c_registermap.h"

ADC_HandleTypeDef hadc1;
DMA_HandleTypeDef hdma_adc1;

I2C_HandleTypeDef hi2c1;
DMA_HandleTypeDef hdma_i2c1_rx;
DMA_HandleTypeDef hdma_i2c1_tx;

TIM_HandleTypeDef htim1;

enum dither_states {DITHER_0 = 0, DITHER_1, DITHER_2};
uint16_t dither_bins[3] = {4095, 2112, 1450};

enum palette_states {PALETTE_0 = 0, PALETTE_1, PALETTE_2, PALETTE_3, PALETTE_4, PALETTE_5};
uint16_t palette_bins[6] = {4095, 2112, 1450, 465, 233, 794};

enum exposure_states {EXPOSURE_0 = 0, EXPOSURE_1, EXPOSURE_2, EXPOSURE_3, EXPOSURE_4};
uint16_t exposure_bins[4] = {4095, 2112, 1450, 605}; // wip, needs to be 5, ordered wrong switch

struct analog_t {
  uint16_t adc[4];
  uint16_t vbat;
  uint8_t binsize;
  uint8_t dither;
  uint8_t palette;
  uint8_t exposure;
} analog = {.binsize = 50};

struct trigger_t {
  uint8_t flag;
  uint16_t r_count;
  uint16_t l_count;
} trigger = {.flag = 0, .r_count = 0, .l_count = 0};

void SystemClock_Config(void);
static void MX_GPIO_Init(void);
static void MX_DMA_Init(void);
static void MX_I2C1_Init(void);
static void MX_ADC1_Init(void);
static void MX_TIM1_Init(void);
void Error_Handler(void);

i2c_client_init_t i2c_init = {.hi2c = &hi2c1, .error_handler = &Error_Handler};

int main(void)
{
  HAL_Init();
  SystemClock_Config();

  MX_GPIO_Init();
  MX_DMA_Init();
  MX_I2C1_Init();
  MX_ADC1_Init();
  MX_TIM1_Init();

  HAL_TIM_Base_Start_IT(&htim1);
  HAL_ADC_Start_DMA(&hadc1, (uint32_t *) &analog.adc[0], 4);

  I2C_Client_Init(&i2c_init);

  I2C_Set_Register(CHIPID01, 13);
  I2C_Set_Register(CHIPID02, 12);

  I2C_Set_Register(FWVERSMA, 0);
  I2C_Set_Register(FWVERSMI, 1);
  I2C_Set_Register(FWVERSPA, 0);

  I2C_Set_Register(DISPLRST, 0);
  I2C_Set_Register(DISPLCSA, 0);
  I2C_Set_Register(DISPLCSB, 0);

  while (1)
  {
    if(trigger.flag == 1){
      trigger.flag = 0;
      HAL_GPIO_WritePin(GPIOB, INT_OUT_Pin, GPIO_PIN_RESET);
      HAL_Delay(1);
      HAL_GPIO_WritePin(GPIOB, INT_OUT_Pin, GPIO_PIN_SET);
    }

    for(uint8_t i = 0; i < sizeof(dither_bins)/2; i++){
      if(analog.adc[1] >= dither_bins[i]-analog.binsize && analog.adc[1] <= dither_bins[i]+analog.binsize){
        // WIP INT flags and sticky int pin
        //if(i != analog.dither){
        //  // set flag and IO
        //}
        analog.dither = i;
      }
    }
    for(uint8_t i = 0; i < sizeof(palette_bins)/2; i++){
      if(analog.adc[2] >= palette_bins[i]-analog.binsize && analog.adc[2] <= palette_bins[i]+analog.binsize){
        // WIP INT flags and sticky int pin
        //if(i != analog.palette){
        //  // set flag and IO
        //}
        analog.palette = i;
      }
    }
    for(uint8_t i = 0; i < sizeof(exposure_bins)/2; i++){
      if(analog.adc[3] >= exposure_bins[i]-analog.binsize && analog.adc[3] <= exposure_bins[i]+analog.binsize){
        // WIP INT flags and sticky int pin
        //if(i != analog.exposure){
        //  // set flag and IO
        //}
        analog.exposure = i;
      }
    }

    analog.vbat = (analog.adc[0]*9900/8192);

    // Return dial positions
    I2C_Set_Register(RSDITHER, analog.dither);
    I2C_Set_Register(RSPALETT, analog.palette);
    I2C_Set_Register(RSEXPOSU, analog.exposure);

    // Return battery level
    I2C_Set_Register(VBATTERY, analog.vbat);

    // Read & return trigger IO, mostly used for debug purporses right now
    I2C_Set_Register(TRIGGERA, HAL_GPIO_ReadPin(GPIOA, TRIGGER_A_Pin));
    I2C_Set_Register(TRIGGERB, HAL_GPIO_ReadPin(GPIOA, TRIGGER_B_Pin));

    // Return trigger counts
    I2C_Set_Register(TRIACNTA, (uint8_t)(trigger.l_count >> 8) & 0xFF);
    I2C_Set_Register(TRIACNTB, (uint8_t)(trigger.l_count & 0xFF));

    I2C_Set_Register(TRIBCNTA, (uint8_t)(trigger.r_count >> 8) & 0xFF);
    I2C_Set_Register(TRIBCNTB, (uint8_t)(trigger.r_count & 0xFF));

    // Display related IO
    HAL_GPIO_WritePin(GPIOB, DISPLAY_RST_Pin, (!I2C_Get_Register(DISPLRST)) & 0x01);
    HAL_GPIO_WritePin(GPIOA, DISPLAY_1_CS_Pin, (!I2C_Get_Register(DISPLCSA)) & 0x01);
    HAL_GPIO_WritePin(GPIOA, DISPLAY_2_CS_Pin, (!I2C_Get_Register(DISPLCSB)) & 0x01);
  }
}

void HAL_GPIO_EXTI_Falling_Callback(uint16_t GPIO_Pin)
{
  if(GPIO_Pin == TRIGGER_A_Pin) {
    trigger.flag = 1;
    trigger.l_count++;
  } else if(GPIO_Pin == TRIGGER_B_Pin) {
    trigger.flag = 1;
    trigger.r_count++;
  } else {
    __NOP();
  }
}

void SystemClock_Config(void)
{
  RCC_OscInitTypeDef RCC_OscInitStruct = {0};
  RCC_ClkInitTypeDef RCC_ClkInitStruct = {0};
  HAL_PWREx_ControlVoltageScaling(PWR_REGULATOR_VOLTAGE_SCALE1);

  RCC_OscInitStruct.OscillatorType = RCC_OSCILLATORTYPE_HSI;
  RCC_OscInitStruct.HSIState = RCC_HSI_ON;
  RCC_OscInitStruct.HSIDiv = RCC_HSI_DIV1;
  RCC_OscInitStruct.HSICalibrationValue = RCC_HSICALIBRATION_DEFAULT;
  RCC_OscInitStruct.PLL.PLLState = RCC_PLL_NONE;
  HAL_RCC_OscConfig(&RCC_OscInitStruct);

  RCC_ClkInitStruct.ClockType = RCC_CLOCKTYPE_HCLK|RCC_CLOCKTYPE_SYSCLK
                              |RCC_CLOCKTYPE_PCLK1;
  RCC_ClkInitStruct.SYSCLKSource = RCC_SYSCLKSOURCE_HSI;
  RCC_ClkInitStruct.AHBCLKDivider = RCC_SYSCLK_DIV1;
  RCC_ClkInitStruct.APB1CLKDivider = RCC_HCLK_DIV1;
  HAL_RCC_ClockConfig(&RCC_ClkInitStruct, FLASH_LATENCY_0);
}

static void MX_ADC1_Init(void)
{
  ADC_ChannelConfTypeDef sConfig = {0};

  hadc1.Instance = ADC1;
  hadc1.Init.ClockPrescaler = ADC_CLOCK_SYNC_PCLK_DIV2;
  hadc1.Init.Resolution = ADC_RESOLUTION_12B;
  hadc1.Init.DataAlign = ADC_DATAALIGN_RIGHT;
  hadc1.Init.ScanConvMode = ADC_SCAN_ENABLE;
  hadc1.Init.EOCSelection = ADC_EOC_SEQ_CONV;
  hadc1.Init.LowPowerAutoWait = DISABLE;
  hadc1.Init.LowPowerAutoPowerOff = DISABLE;
  hadc1.Init.ContinuousConvMode = DISABLE;
  hadc1.Init.NbrOfConversion = 4;
  hadc1.Init.DiscontinuousConvMode = DISABLE;
  hadc1.Init.ExternalTrigConv = ADC_EXTERNALTRIG_T1_TRGO2;
  hadc1.Init.ExternalTrigConvEdge = ADC_EXTERNALTRIGCONVEDGE_RISING;
  hadc1.Init.DMAContinuousRequests = ENABLE;
  hadc1.Init.Overrun = ADC_OVR_DATA_OVERWRITTEN;
  hadc1.Init.SamplingTimeCommon1 = ADC_SAMPLETIME_19CYCLES_5;
  hadc1.Init.SamplingTimeCommon2 = ADC_SAMPLETIME_1CYCLE_5;
  hadc1.Init.OversamplingMode = DISABLE;
  hadc1.Init.TriggerFrequencyMode = ADC_TRIGGER_FREQ_HIGH;
  HAL_ADC_Init(&hadc1);

  sConfig.Channel = ADC_CHANNEL_0;
  sConfig.Rank = ADC_REGULAR_RANK_1;
  sConfig.SamplingTime = ADC_SAMPLINGTIME_COMMON_1;
  HAL_ADC_ConfigChannel(&hadc1, &sConfig);

  sConfig.Channel = ADC_CHANNEL_1;
  sConfig.Rank = ADC_REGULAR_RANK_2;
  HAL_ADC_ConfigChannel(&hadc1, &sConfig);

  sConfig.Channel = ADC_CHANNEL_2;
  sConfig.Rank = ADC_REGULAR_RANK_3;
  HAL_ADC_ConfigChannel(&hadc1, &sConfig);

  sConfig.Channel = ADC_CHANNEL_3;
  sConfig.Rank = ADC_REGULAR_RANK_4;
  HAL_ADC_ConfigChannel(&hadc1, &sConfig);
}

static void MX_I2C1_Init(void)
{
  hi2c1.Instance = I2C1;
  hi2c1.Init.Timing = 0x00300617;
  hi2c1.Init.OwnAddress1 = 84;
  hi2c1.Init.AddressingMode = I2C_ADDRESSINGMODE_7BIT;
  hi2c1.Init.DualAddressMode = I2C_DUALADDRESS_DISABLE;
  hi2c1.Init.OwnAddress2 = 0;
  hi2c1.Init.OwnAddress2Masks = I2C_OA2_NOMASK;
  hi2c1.Init.GeneralCallMode = I2C_GENERALCALL_DISABLE;
  hi2c1.Init.NoStretchMode = I2C_NOSTRETCH_DISABLE;
  HAL_I2C_Init(&hi2c1);
  HAL_I2CEx_ConfigAnalogFilter(&hi2c1, I2C_ANALOGFILTER_ENABLE);
  HAL_I2CEx_ConfigDigitalFilter(&hi2c1, 0);
}

static void MX_TIM1_Init(void)
{
  TIM_ClockConfigTypeDef sClockSourceConfig = {0};
  TIM_MasterConfigTypeDef sMasterConfig = {0};

  htim1.Instance = TIM1;
  htim1.Init.Prescaler = 10;
  htim1.Init.CounterMode = TIM_COUNTERMODE_UP;
  htim1.Init.Period = 15999;
  htim1.Init.ClockDivision = TIM_CLOCKDIVISION_DIV1;
  htim1.Init.RepetitionCounter = 0;
  htim1.Init.AutoReloadPreload = TIM_AUTORELOAD_PRELOAD_ENABLE;
  HAL_TIM_Base_Init(&htim1);

  sClockSourceConfig.ClockSource = TIM_CLOCKSOURCE_INTERNAL;
  HAL_TIM_ConfigClockSource(&htim1, &sClockSourceConfig);

  sMasterConfig.MasterOutputTrigger = TIM_TRGO_RESET;
  sMasterConfig.MasterOutputTrigger2 = TIM_TRGO2_UPDATE;
  sMasterConfig.MasterSlaveMode = TIM_MASTERSLAVEMODE_DISABLE;
  HAL_TIMEx_MasterConfigSynchronization(&htim1, &sMasterConfig);
}

static void MX_DMA_Init(void)
{
  __HAL_RCC_DMA1_CLK_ENABLE();

  HAL_NVIC_SetPriority(DMA1_Channel1_IRQn, 0, 0);
  HAL_NVIC_EnableIRQ(DMA1_Channel1_IRQn);
  HAL_NVIC_SetPriority(DMA1_Channel2_3_IRQn, 0, 0);
  HAL_NVIC_EnableIRQ(DMA1_Channel2_3_IRQn);
}

static void MX_GPIO_Init(void)
{
  GPIO_InitTypeDef GPIO_InitStruct = {0};

  __HAL_RCC_GPIOB_CLK_ENABLE();
  __HAL_RCC_GPIOA_CLK_ENABLE();

  HAL_GPIO_WritePin(GPIOA, DISPLAY_1_CS_Pin|DISPLAY_2_CS_Pin, GPIO_PIN_SET);

  HAL_GPIO_WritePin(GPIOB, DISPLAY_RST_Pin|INT_OUT_Pin, GPIO_PIN_SET);

  GPIO_InitStruct.Pin = TRIGGER_A_Pin|TRIGGER_B_Pin;
  GPIO_InitStruct.Mode = GPIO_MODE_IT_FALLING;
  GPIO_InitStruct.Pull = GPIO_NOPULL;
  HAL_GPIO_Init(GPIOA, &GPIO_InitStruct);

  GPIO_InitStruct.Pin = DISPLAY_1_CS_Pin|DISPLAY_2_CS_Pin;
  GPIO_InitStruct.Mode = GPIO_MODE_OUTPUT_PP;
  GPIO_InitStruct.Pull = GPIO_NOPULL;
  GPIO_InitStruct.Speed = GPIO_SPEED_FREQ_LOW;
  HAL_GPIO_Init(GPIOA, &GPIO_InitStruct);

  GPIO_InitStruct.Pin = DISPLAY_RST_Pin|INT_OUT_Pin;
  GPIO_InitStruct.Mode = GPIO_MODE_OUTPUT_PP;
  GPIO_InitStruct.Pull = GPIO_NOPULL;
  GPIO_InitStruct.Speed = GPIO_SPEED_FREQ_LOW;
  HAL_GPIO_Init(GPIOB, &GPIO_InitStruct);

  HAL_NVIC_SetPriority(EXTI4_15_IRQn, 0, 0);
  HAL_NVIC_EnableIRQ(EXTI4_15_IRQn);
}

void Error_Handler(void)
{
  __disable_irq();
  while (1)
  {
  }
}

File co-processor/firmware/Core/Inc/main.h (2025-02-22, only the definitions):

#define VBAT_Pin GPIO_PIN_0
#define VBAT_GPIO_Port GPIOA
#define DITHER_Pin GPIO_PIN_1
#define DITHER_GPIO_Port GPIOA
#define PALETTE_Pin GPIO_PIN_2
#define PALETTE_GPIO_Port GPIOA
#define EXPOSURE_Pin GPIO_PIN_3
#define EXPOSURE_GPIO_Port GPIOA
#define TRIGGER_A_Pin GPIO_PIN_4
#define TRIGGER_A_GPIO_Port GPIOA
#define TRIGGER_A_EXTI_IRQn EXTI4_15_IRQn
#define TRIGGER_B_Pin GPIO_PIN_5
#define TRIGGER_B_GPIO_Port GPIOA
#define TRIGGER_B_EXTI_IRQn EXTI4_15_IRQn
#define DISPLAY_1_CS_Pin GPIO_PIN_6
#define DISPLAY_1_CS_GPIO_Port GPIOA
#define DISPLAY_2_CS_Pin GPIO_PIN_7
#define DISPLAY_2_CS_GPIO_Port GPIOA
#define DISPLAY_RST_Pin GPIO_PIN_0
#define DISPLAY_RST_GPIO_Port GPIOB
#define INT_OUT_Pin GPIO_PIN_3
#define INT_OUT_GPIO_Port GPIOB

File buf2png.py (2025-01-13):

import struct
import zlib
import sys

class PngImage:
  def __init__(self, width, height, colormode, colordepth):
    self.width = width
    self.height = height
    self.colormode = colormode
    self.colordepth = colordepth
    self.palette = [ 0x0d2b45,
                     0x203c56,
                     0x544e68,
                     0x8d697a,
                     0xd08159,
                     0xffaa5e,
                     0xffd4a3,
                     0xffecd6 ]

  def buildPalette(self, pal):
    colors = bytearray()
    pallen = int(256/len(pal))
    for i in pal:
      for _ in range(pallen):
        colors.extend(i.to_bytes(3))
    return colors

  def createChunk(self, buf, type, data):
    crc = zlib.crc32(type + data)
    buf.extend(len(data).to_bytes(4, 'big') + type + data + crc.to_bytes(4, 'big'))

  def filterAndCompressImage(self, buf):
    filteredbuf = bytearray()
    for i in range(0, self.height):
      filteredbuf.extend(bytes(1) + buf[i*self.width:i*self.width+self.width])
    return zlib.compress(filteredbuf)

  def buildPng(self, buf):
    pngbuf = bytearray(struct.pack('>B3sHBB', 0x89, b'PNG', 0x0D0A, 0x1A, 0x0A))
    self.createChunk(pngbuf, b'IHDR', struct.pack('>IIBBBBB', self.width, self.height, self.colordepth, self.colormode, 0, 0, 0))
    self.createChunk(pngbuf, b'PLTE', self.buildPalette(self.palette))
    self.createChunk(pngbuf, b'IDAT', self.filterAndCompressImage(buf))
    self.createChunk(pngbuf, b'IEND', b'')
    return pngbuf

if __name__ == '__main__':

  pngimg = PngImage(400, 296, 3, 8)

  with open(sys.argv[1], "rb") as f:
    with open(sys.argv[2], "wb") as w:
      w.write(pngimg.buildPng(f.read()))
      w.close()
    f.close()

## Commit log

2025-01-26 added camera settings, expanded todo list
2025-02-09 updated hw
    [picsy-hw.kicad_pcb, picsy-hw.kicad_sch]
2025-02-22 updated hw files
    [picsy-hw.kicad_pcb, picsy-hw.kicad_sch]
2025-02-22 added scad file, case v1
    [PICSY.scad]
2025-02-22 updated schematic
    [picsy-hw.kicad_sch]
2025-02-22 added initial STM32 firmware
2025-02-22 added i2c functionality to FW
2025-02-22 added new frontplate
    [PICSY.scad]
2025-02-22 added STLs
    [PICSY_back_plate.stl, PICSY_bottom_cover.stl, PICSY_button_inlay.stl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]
2025-02-22 updated schematic todo
    [picsy-hw.kicad_sch]
2025-02-25 fixed off by one bug
    [boot.py]

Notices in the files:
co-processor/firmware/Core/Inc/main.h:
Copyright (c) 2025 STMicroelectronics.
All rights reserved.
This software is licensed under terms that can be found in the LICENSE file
